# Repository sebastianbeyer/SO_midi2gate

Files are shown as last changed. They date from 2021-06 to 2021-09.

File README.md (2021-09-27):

Simple Midi to gate module with 12 gates. It's in the
[KOSMO format](https://www.lookmumnocomputer.com/modular)
made by Look Mum No Computer (20cm high, 7.5cm wide). Gates are 5V.

<p float="middle">
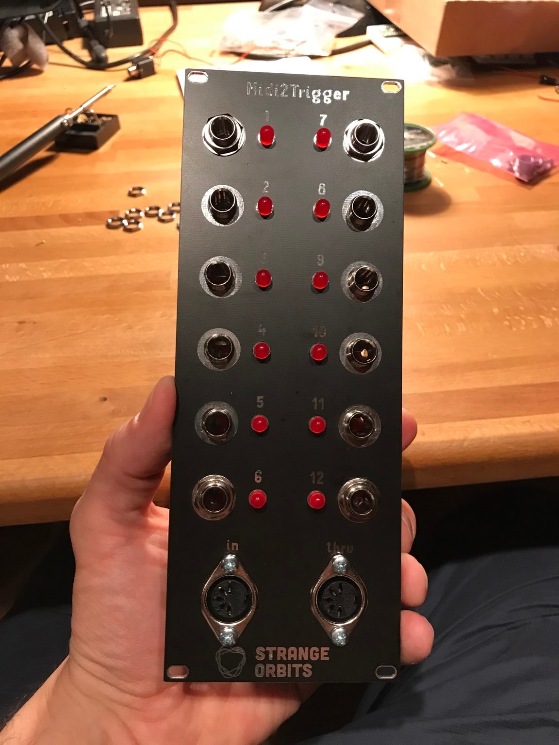
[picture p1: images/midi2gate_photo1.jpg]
  
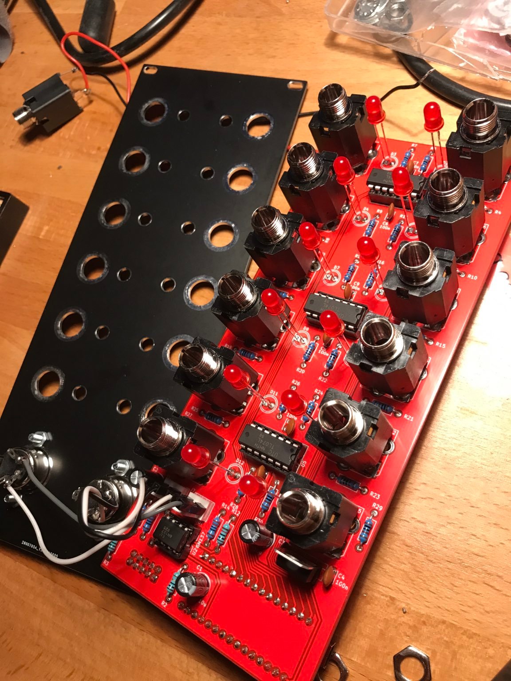
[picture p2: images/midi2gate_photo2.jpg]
  
</p>

## How to get it

Download the [lates release](https://github.com/sebastianbeyer/SO_midi2gate/releases/latest)
including the gerber files and Arduino code

## Arduino code

The code can be found in the code directory and requires only a
[midi library](https://github.com/FortySevenEffects/arduino_midi_library).
Install instructions for this lib can be found
[in the repo](https://github.com/FortySevenEffects/arduino_midi_library#getting-started).

## Schematic

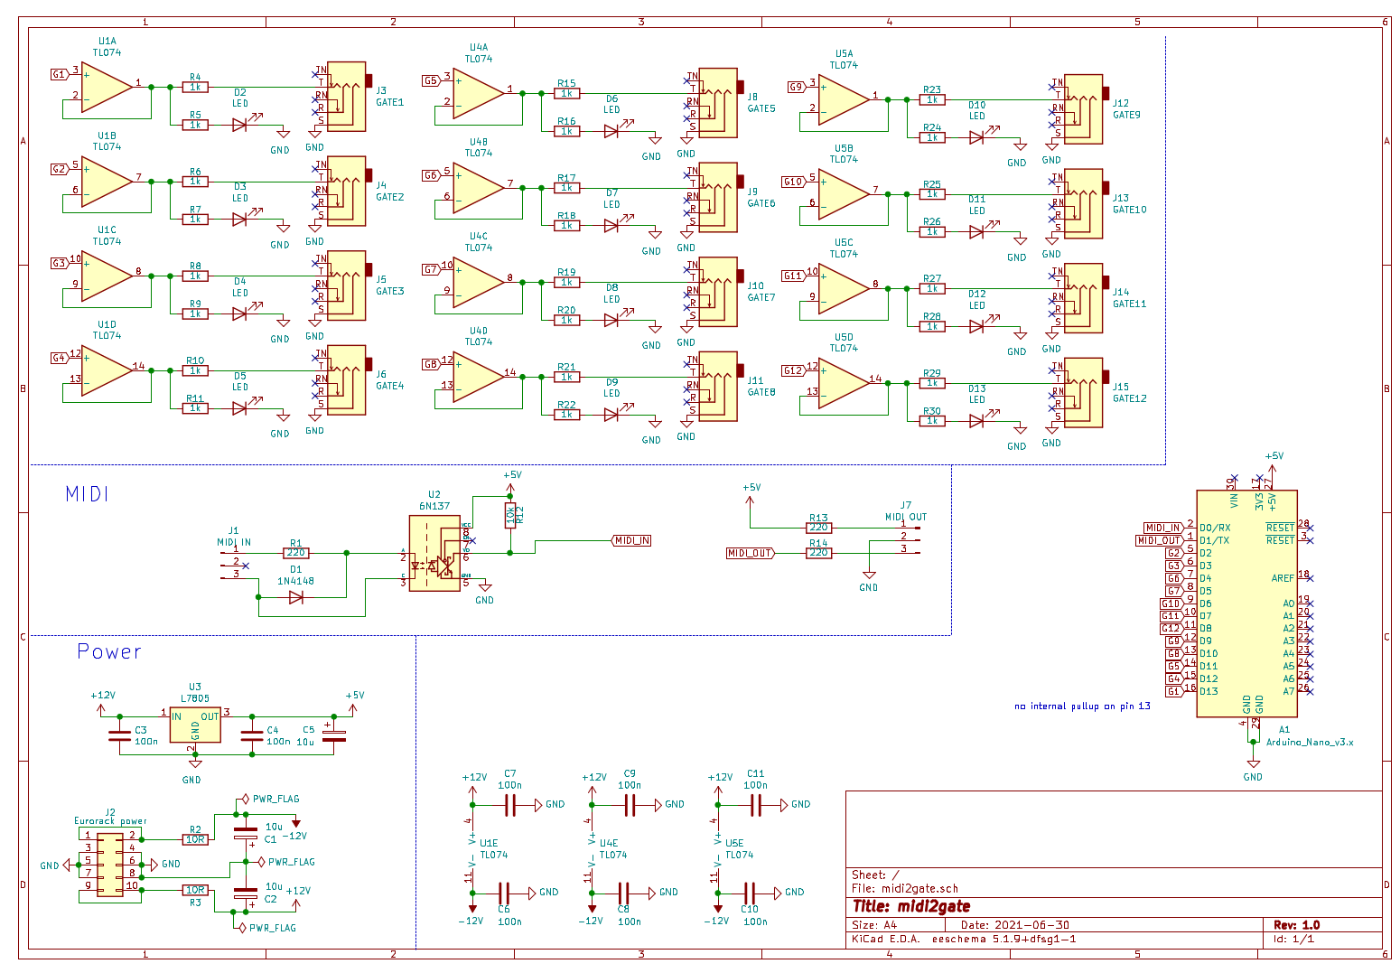
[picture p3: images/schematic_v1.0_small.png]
schematic


## BOM

| Reference| Quantity | Value | Description |
| --- | --- | ----- | --- |
| A1  | 1 |  Arduino Nano | |
| C1, C2, C5 | 3 | 10u | EL cap |
| C3, C4, C6, C7, C8, C9, C10, C11 | 8 |100n | ceramic disc cap |
| D1 | 1 | 1N4148 | diode |
| D2, D3, D4, D5, D6, D7, D8, D9, D10, D11, D12, D13 | 12 | LED | legs should be
25mm long|
| J1, J2 | 2 | MIDI jacks | |
| J1, J2 | 2 | Molex 3pin  | for MIDI jacks, you can also solder directly |
| J3, ... J15 |12 | Large jack sockets | |
| R1, R13, R14 | 3 | 220 | |
| R2, R3 | 2 | 10R | |
| R4, R5, R6, R7, R8, R9, R10, R11, R15, R16, R17, R18, R19, R20, R21, R22, R23, R24, R25, R26, R27, R28, R29, R30 | 24 |1k | |
| R12 | 1 | 10k |  |
| U1, U4, U5 | 3 | TL074 | opamp |
| U2 | 1 | 6N137 | optocoupler for midi |
| U3 | 1 | L7805 | 5V regulator |

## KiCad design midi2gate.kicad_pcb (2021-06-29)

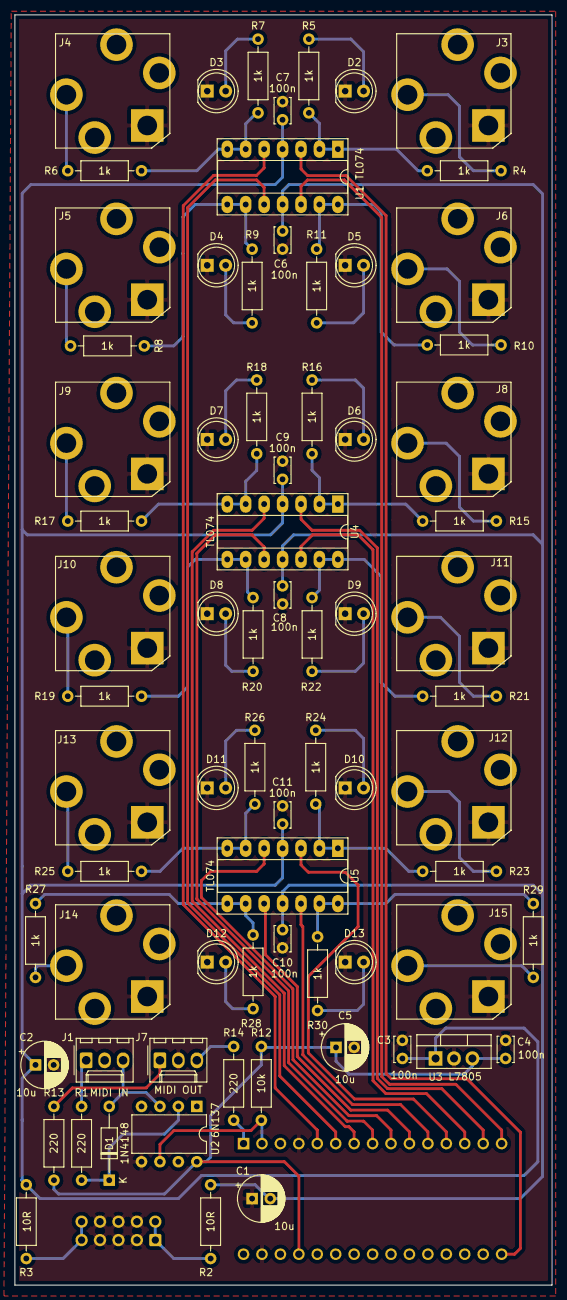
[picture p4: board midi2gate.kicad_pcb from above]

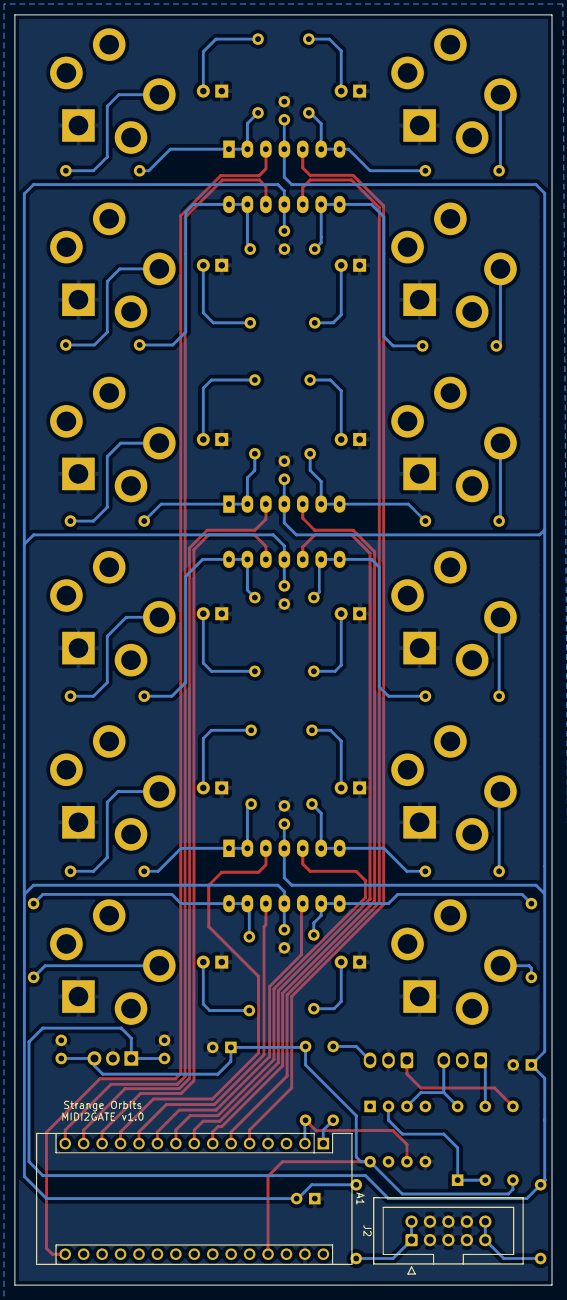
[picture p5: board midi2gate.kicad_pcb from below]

Board: 2 copper layers, 74.0 x 175.0 mm, 75 parts (2 on the bottom side), 61 nets.

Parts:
A1: Arduino_Nano_v3.x; Arduino_Nano
C1, C2, C5: 10u; CP_Radial_D6.3mm_P2.50mm
C3, C4, C6, C7, C8, C9, C10, C11: 100n; C_Disc_D3.4mm_W2.1mm_P2.50mm
D1: 1N4148; D_DO-35_SOD27_P10.16mm_Horizontal
D2, D3, D4, D5, D6, D7, D8, D9, D10, D11, D12, D13: LED; LED_D5.0mm
J1: MIDI IN; Molex_KK-254_AE-6410-03A_1x03_P2.54mm_Vertical
J2: Eurorack power; IDC-Header_2x05_P2.54mm_Vertical
J3: GATE1; Jack_6.35mm_PJ_629HAN
J4: GATE2; Jack_6.35mm_PJ_629HAN
J5: GATE3; Jack_6.35mm_PJ_629HAN
J6: GATE4; Jack_6.35mm_PJ_629HAN
J7: MIDI OUT; Molex_KK-254_AE-6410-03A_1x03_P2.54mm_Vertical
J8: GATE5; Jack_6.35mm_PJ_629HAN
J9: GATE6; Jack_6.35mm_PJ_629HAN
J10: GATE7; Jack_6.35mm_PJ_629HAN
J11: GATE8; Jack_6.35mm_PJ_629HAN
J12: GATE9; Jack_6.35mm_PJ_629HAN
J13: GATE10; Jack_6.35mm_PJ_629HAN
J14: GATE11; Jack_6.35mm_PJ_629HAN
J15: GATE12; Jack_6.35mm_PJ_629HAN
R1, R13, R14: 220; R_Axial_DIN0207_L6.3mm_D2.5mm_P7.62mm_Horizontal_silkvalue
R2, R3: 10R; R_Axial_DIN0207_L6.3mm_D2.5mm_P7.62mm_Horizontal_silkvalue
R4, R5, R6, R7, R8, R9, R10, R11, R15, R16, R17, R18, R19, R20, R21, R22, R23, R24, R25, R26, R27, R28, R29, R30: 1k; R_Axial_DIN0207_L6.3mm_D2.5mm_P7.62mm_Horizontal_silkvalue
R12: 10k; R_Axial_DIN0207_L6.3mm_D2.5mm_P7.62mm_Horizontal_silkvalue
U1, U4, U5: TL074; DIP-14_W7.62mm_Socket_LongPads
U2: 6N137; DIP-8_W7.62mm
U3: L7805; TO-220-3_Vertical

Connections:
+5V: A1.27, C4.1, C5.1, R12.1, R13.1, U2.8, U3.3
+12V: C2.1, C3.1, C7.2, C9.2, C11.2, R3.2, U1.4, U3.1, U4.4, U5.4
-12V: C1.2, C6.2, C8.2, C10.2, R2.2, U1.11, U4.11, U5.11
G1: A1.16, U1.3
G2: A1.5, U1.5
G3: A1.6, U1.10
G4: A1.15, U1.12
G5: A1.14, U4.3
G6: A1.7, U4.5
G7: A1.8, U4.10
G8: A1.13, U4.12
G9: A1.12, U5.3
G10: A1.9, U5.5
G11: A1.10, U5.10
G12: A1.11, U5.12
GND: A1.4, A1.29, C1.1, C2.2, C3.2, C4.2, C5.2, C6.1, C7.1, C8.1, C9.1, C10.1, C11.1, D2.1, D3.1, D4.1, D5.1, D6.1, D7.1, D8.1, D9.1, D10.1, D11.1, D12.1, D13.1, J2.3, J2.4, J2.5, J2.6, J2.7, J2.8, J3.S, J4.S, J5.S, J6.S, J7.2, J8.S, J9.S, J10.S, J11.S, J12.S, J13.S, J14.S, J15.S, U2.5, U3.2
MIDI_IN: A1.2, R12.2, U2.6
MIDI_OUT: A1.1, R14.1
unnamed: D1.1, R1.2, U2.2
unnamed: D1.2, J1.3, U2.3
unnamed: D2.2, R5.2
unnamed: D3.2, R7.2
unnamed: D4.2, R9.2
unnamed: D5.2, R11.2
unnamed: D6.2, R16.2
unnamed: D7.2, R18.2
unnamed: D8.2, R20.2
unnamed: D9.2, R22.2
unnamed: D10.2, R24.2
unnamed: D11.2, R26.2
unnamed: D12.2, R28.2
unnamed: D13.2, R30.2
unnamed: J1.1, R1.1
unnamed: J2.1, J2.2, R2.1
unnamed: J2.9, J2.10, R3.1
unnamed: J3.T, R4.2
unnamed: J4.T, R6.2
unnamed: J5.T, R8.2
unnamed: J6.T, R10.2
unnamed: J7.1, R13.2
unnamed: J7.3, R14.2
unnamed: J8.T, R15.2
unnamed: J9.T, R17.2
unnamed: J10.T, R19.2
unnamed: J11.T, R21.2
unnamed: J12.T, R23.2
unnamed: J13.T, R25.2
unnamed: J14.T, R27.2
unnamed: J15.T, R29.2
unnamed: R4.1, R5.1, U1.1, U1.2
unnamed: R6.1, R7.1, U1.6, U1.7
unnamed: R8.1, R9.1, U1.8, U1.9
unnamed: R10.1, R11.1, U1.13, U1.14
unnamed: R15.1, R16.1, U4.1, U4.2
unnamed: R17.1, R18.1, U4.6, U4.7
unnamed: R19.1, R20.1, U4.8, U4.9
unnamed: R21.1, R22.1, U4.13, U4.14
unnamed: R23.1, R24.1, U5.1, U5.2
unnamed: R25.1, R26.1, U5.6, U5.7
unnamed: R27.1, R28.1, U5.8, U5.9
unnamed: R29.1, R30.1, U5.13, U5.14

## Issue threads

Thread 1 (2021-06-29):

Weird blinking at startup

sebastianbeyer, 2021-06-29:
Probably needs external pulldown resistors for all the gates, because Arduino internal resistors only work after booting. Not a huge problem though :)

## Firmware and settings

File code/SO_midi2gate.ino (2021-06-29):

#include <MIDI.h>

// Using the https://github.com/FortySevenEffects/arduino_midi_library/ library
// this means that midi-thru is enabled by default :-)
// @TODO: github link
//

// Settings

// MIDI channel to listen to (1-16, omni is not supported currently).
constexpr byte MIDI_CHANNEL = 10;

// MIDI note to map to the first LED.
constexpr byte FIRST_NOTE = 36;

// Do a quick LED self-test when booting. Set to false to disable.
constexpr bool SELFTEST = false;

constexpr byte GATE01 = 2;
constexpr byte GATE02 = 3;
constexpr byte GATE03 = 4;
constexpr byte GATE04 = 5;
constexpr byte GATE05 = 6;
constexpr byte GATE06 = 7;
constexpr byte GATE07 = 13;
constexpr byte GATE08 = 12;
constexpr byte GATE09 = 11;
constexpr byte GATE10 = 10;
constexpr byte GATE11 = 9;
constexpr byte GATE12 = 8;


byte gates[] = {GATE01, GATE02, GATE03, GATE04, GATE05, GATE06, GATE07, GATE08, GATE09, GATE10, GATE11, GATE12};
byte current_gate;
constexpr int ngates = 12;



uint8_t i;

MIDI_CREATE_DEFAULT_INSTANCE();

void handleNoteOn(byte channel, byte note, byte velocity)
{
    if (channel == MIDI_CHANNEL){
      digitalWrite(gates[note-FIRST_NOTE], HIGH);
    }
}

void handleNoteOff(byte channel, byte note, byte velocity)
{
  if (channel == MIDI_CHANNEL){
      digitalWrite(gates[note-FIRST_NOTE], LOW);
    }
}

void setup()
{
    for( i = 0; i < ngates; ++i ){
      pinMode(gates[i], OUTPUT);
      digitalWrite(gates[i], LOW);
    }

    MIDI.setHandleNoteOn(handleNoteOn);
    MIDI.setHandleNoteOff(handleNoteOff);

    // Use OMNI channel here, to midi thru on everything
    // not sure if necessary... @TODO: check!
    MIDI.begin(MIDI_CHANNEL_OMNI);


    if (SELFTEST) {
      for( i = 0; i < ngates; ++i ){
        delay(100);
        digitalWrite(gates[i], HIGH);
      }
      delay(100);
      for( i = 0; i < ngates; ++i ){
        digitalWrite(gates[i], LOW);
      }
    }
}

void loop()
{   MIDI.read();
}

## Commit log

2020-11-29 add libs and footprints
2020-12-01 more work
    [freezer.kicad_pcb, freezer.sch]
2020-12-02 before moving the DAC ADC chips
    [freezer.kicad_pcb, freezer.sch]
2020-12-06 routing done!
    [freezer.kicad_pcb, freezer.sch]
2021-02-25 new trigger panel
    [freezer.kicad_pcb, freezer.sch, midi2trigger.kicad_pcb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]
2021-06-29 as sent to jlcpcb
    [midi2trigger.kicad_pcb, midi2trigger.sch]
2021-06-29 add arduino code
2021-06-29 rename midi2trigger -> midi2gate
    [midi2gate.kicad_pcb, midi2gate.sch]
2021-06-29 fix schematic
2021-06-29 fix schematic2
2021-06-29 add BOM
2021-06-29 add arduino
2021-06-30 rearrange schematic like it is in the readme now
    [midi2gate.sch]
2021-06-30 add note about KOSMO format and 5V gates
2021-06-30 add note on LEDs
